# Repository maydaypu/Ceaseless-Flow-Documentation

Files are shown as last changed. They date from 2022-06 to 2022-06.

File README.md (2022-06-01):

# Ceaseless-Flow-Documentation
Ceaseless Flow is a decorative luminaire designed to bring tranquility to an acupuncture clinic waiting room.
By Josephine Wang and Jingyao Shao

This repository includes supplemental paperwork in PDF, 3D model CAD files, and PCB design files.

The 4chLED_PCB_Code.ino can be programmed on ATTINY84 via Arduino ISP. Learn more on https://github.com/SpenceKonde/ATTinyCore/blob/master/avr/extras/ATtiny_x4.md

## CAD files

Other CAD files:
CAD/Ceaseless Flow - Lamp Model.dwg

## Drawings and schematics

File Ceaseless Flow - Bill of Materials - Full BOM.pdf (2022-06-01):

Ceaseless Flow - Bill of Materials | Full BOM

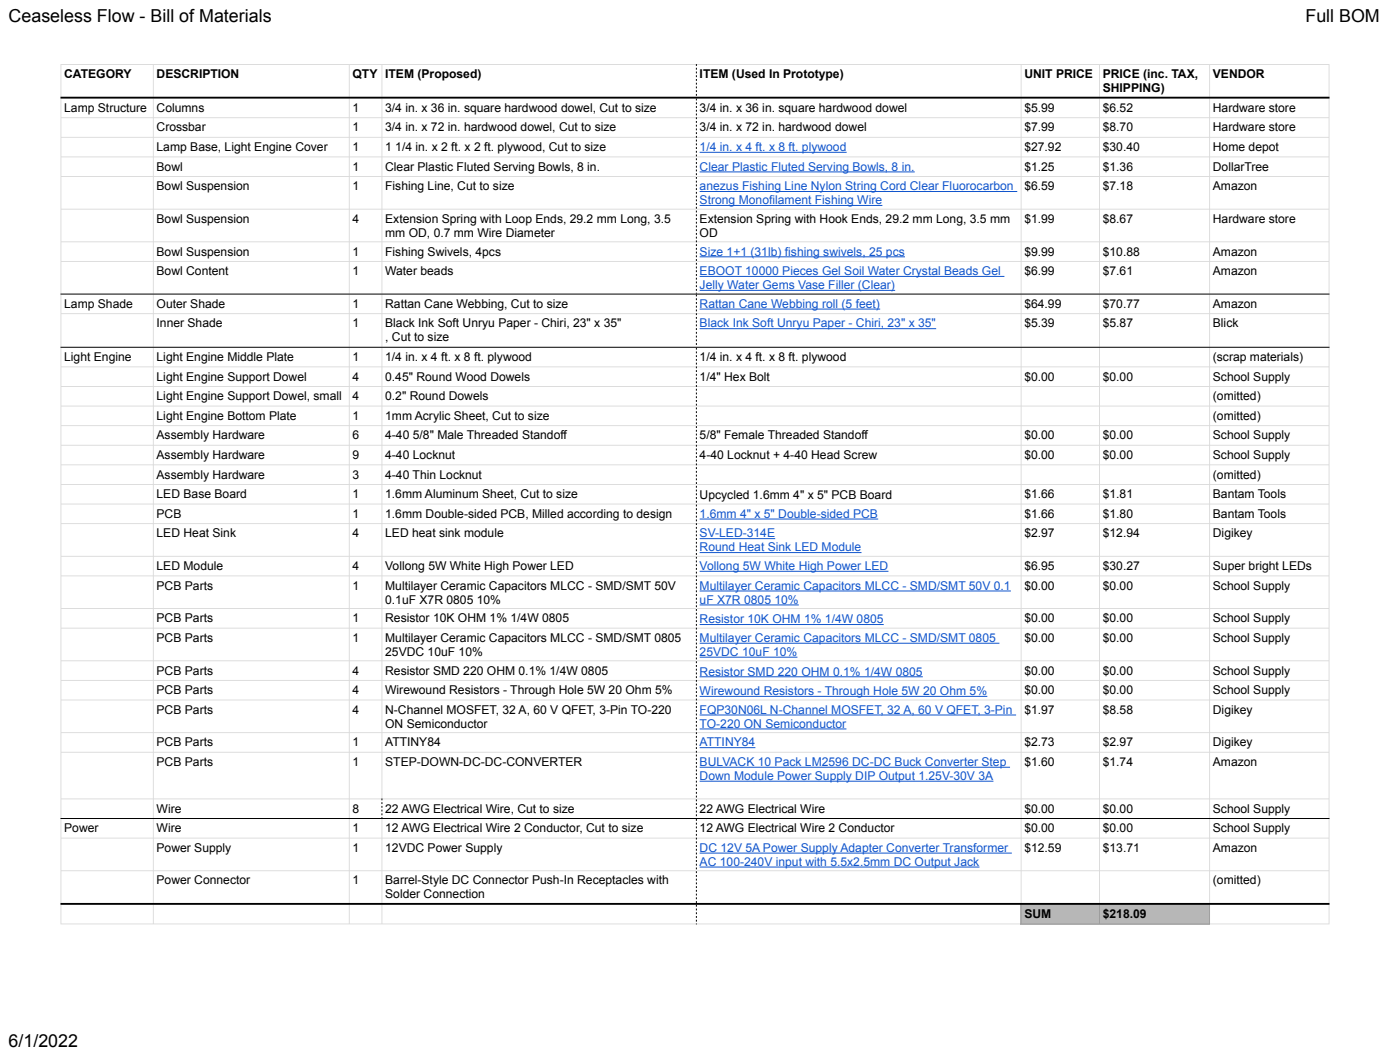
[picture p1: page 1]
CATEGORY; DESCRIPTION; QTY ITEM (Proposed); ITEM (Used In Prototype); UNIT PRICE PRICE (inc. TAX,; SHIPPING); VENDOR; Lamp Structure Columns; 3/4 in. x 36 in. square hardwood dowel, Cut to size; 3/4 in. x 36 in. square hardwood dowel; Hardware store; Crossbar; 3/4 in. x 72 in. hardwood dowel, Cut to size; 3/4 in. x 72 in. hardwood dowel; Lamp Base, Light Engine Cover; 1 1/4 in. x 2 ft. x 2 ft. plywood, Cut to size; 1/4 in. x 4 ft. x 8 ft. plywood; Home depot; Bowl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

Strong Monofilament Fishing Wire (https://www.amazon.com/Anezus-Fishing-String-Fluorocarbon-Monofilament/dp/B07J62FVCV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)
Extension Spring with Hook Ends, 29.2 mm Long, 3.5 mm

mm OD, 0.7 mm Wire Diameter

Jelly Water Gems Vase Filler (Clear) (https://www.amazon.com/gp/product/B01LXKOW8Y/ref=ppx_yo_dt_b_asin_title_o05_s00?ie=UTF8&psc=1)

, Cut to size

Round Heat Sink LED Module (https://www.digikey.com/en/products/detail/ohmite/SV-LED-314E/3768525)

Multilayer Ceramic Capacitors MLCC - SMD/SMT 50V 0.1

Multilayer Ceramic Capacitors MLCC - SMD/SMT 0805
25VDC 10uF 10% (https://www.mouser.com/ProductDetail/TDK/C2012X7S1E106K125AE?qs=P1JMDcb91o5L0SBQ9NWlYQ%3D%3D)

FQP30N06L N-Channel MOSFET, 32 A, 60 V QFET, 3-Pin
TO-220 ON Semiconductor (https://www.digikey.com/en/products/detail/onsemi/FQP30N06L/1055122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)

Down Module Power Supply DIP Output 1.25V-30V 3A

AC 100-240V input with 5.5x2.5mm DC Output Jack (https://www.amazon.com/dp/B01GEA8PQA?psc=1&ref=ppx_yo2ov_dt_b_product_details)

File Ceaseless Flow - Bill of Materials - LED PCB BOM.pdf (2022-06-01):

Ceaseless Flow - Bill of Materials | LED PCB BOM

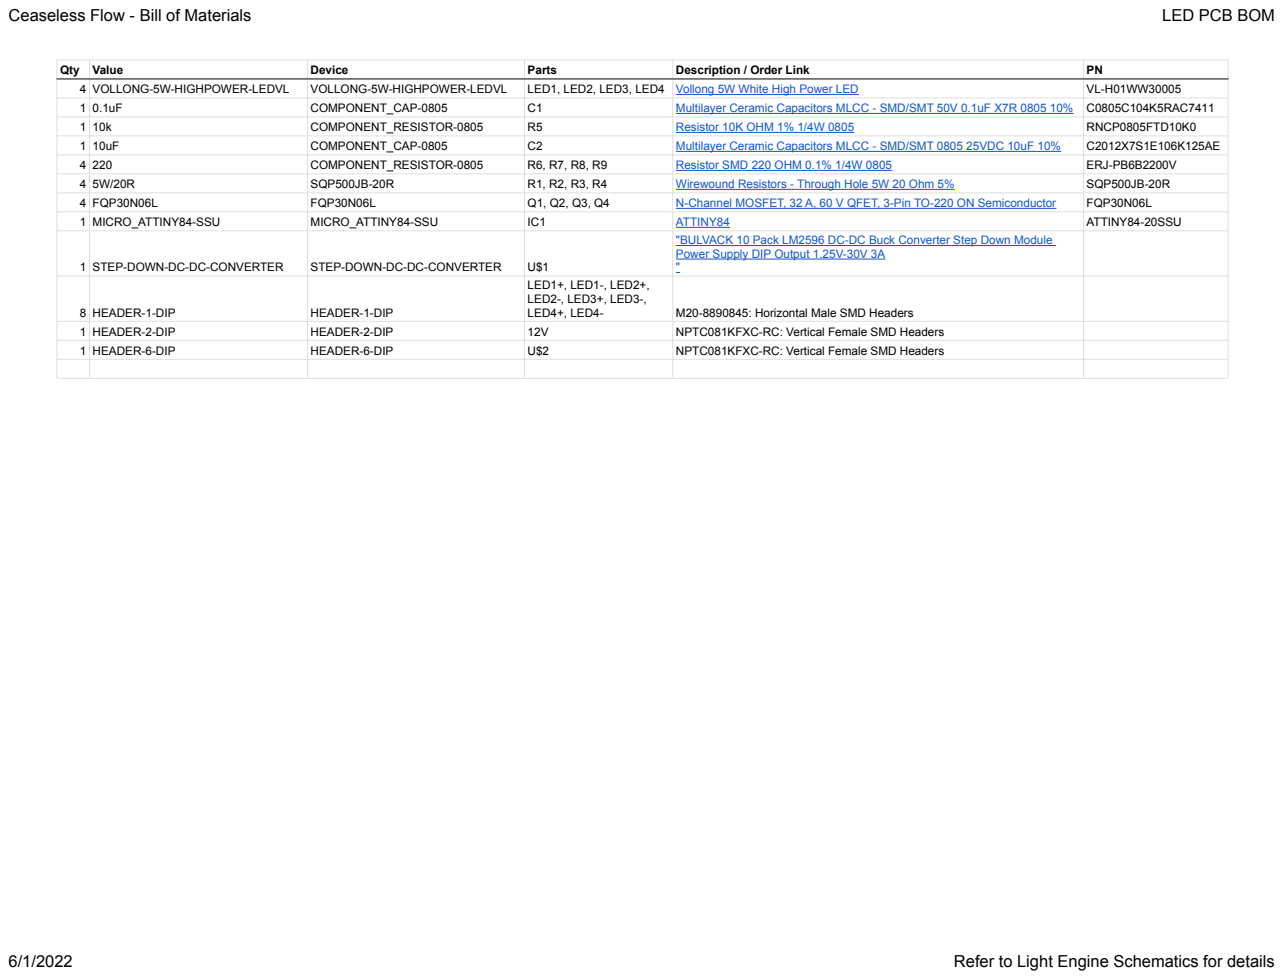
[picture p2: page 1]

"BULVACK 10 Pack LM2596 DC-DC Buck Converter Step Down Module
Power Supply DIP Output 1.25V-30V 3A

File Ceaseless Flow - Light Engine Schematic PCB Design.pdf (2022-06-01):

# Ceaseless Flow

Light Engine Schematic and PCB Design Overview

Designed by:
Josephine Wang and Jingyao Shao

Notes:
Refer to the file Bill of Materials, Sheet ‘LED PCB BOM’ for component specification.
Refer to the folder PCB for the EAGLE or Fusion PCB board design. The PCB can be made on a desktop PCB milling machine (https://www.bantamtools.com/pcb-milling-machine) or ordered from suppliers like OSHPark, (https://oshpark.com/) PCBWay. (https://www.pcbway.com/)
Refer to the file Lamp Construction Drawings, Sheet 3 - Light Engine Assembly Drawings for detailed assembly instruction.

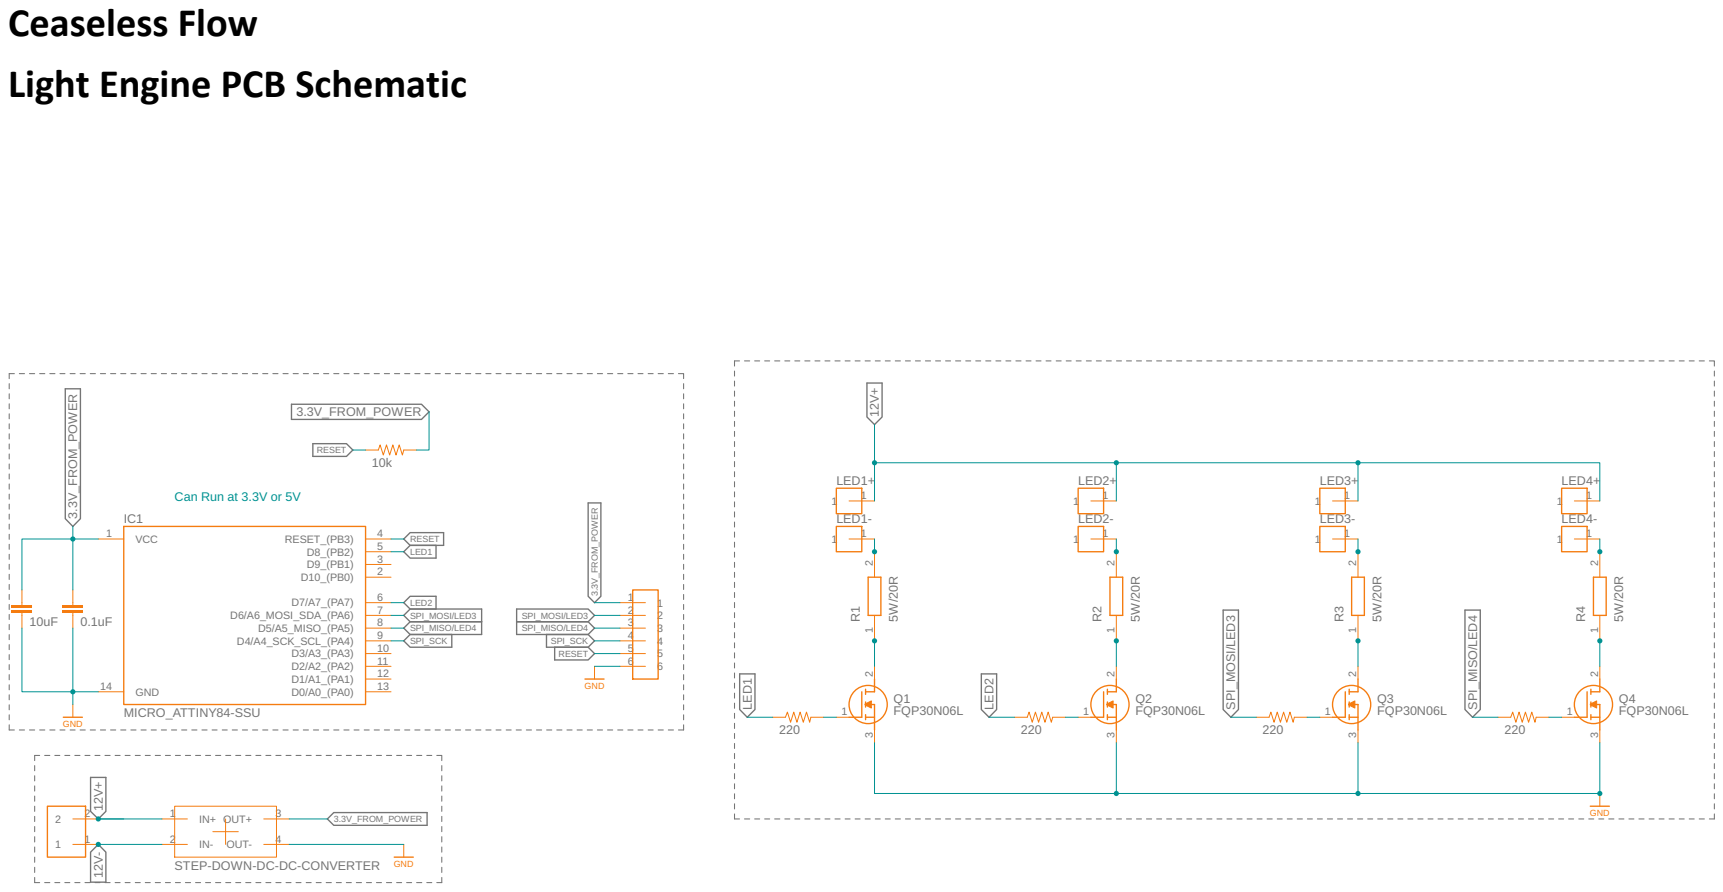
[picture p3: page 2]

Ceaseless Flow
Light Engine PCB Schematic

Can Run at 3.3V or 5V

STEP-DOWN-DC-DC-CONVERTER

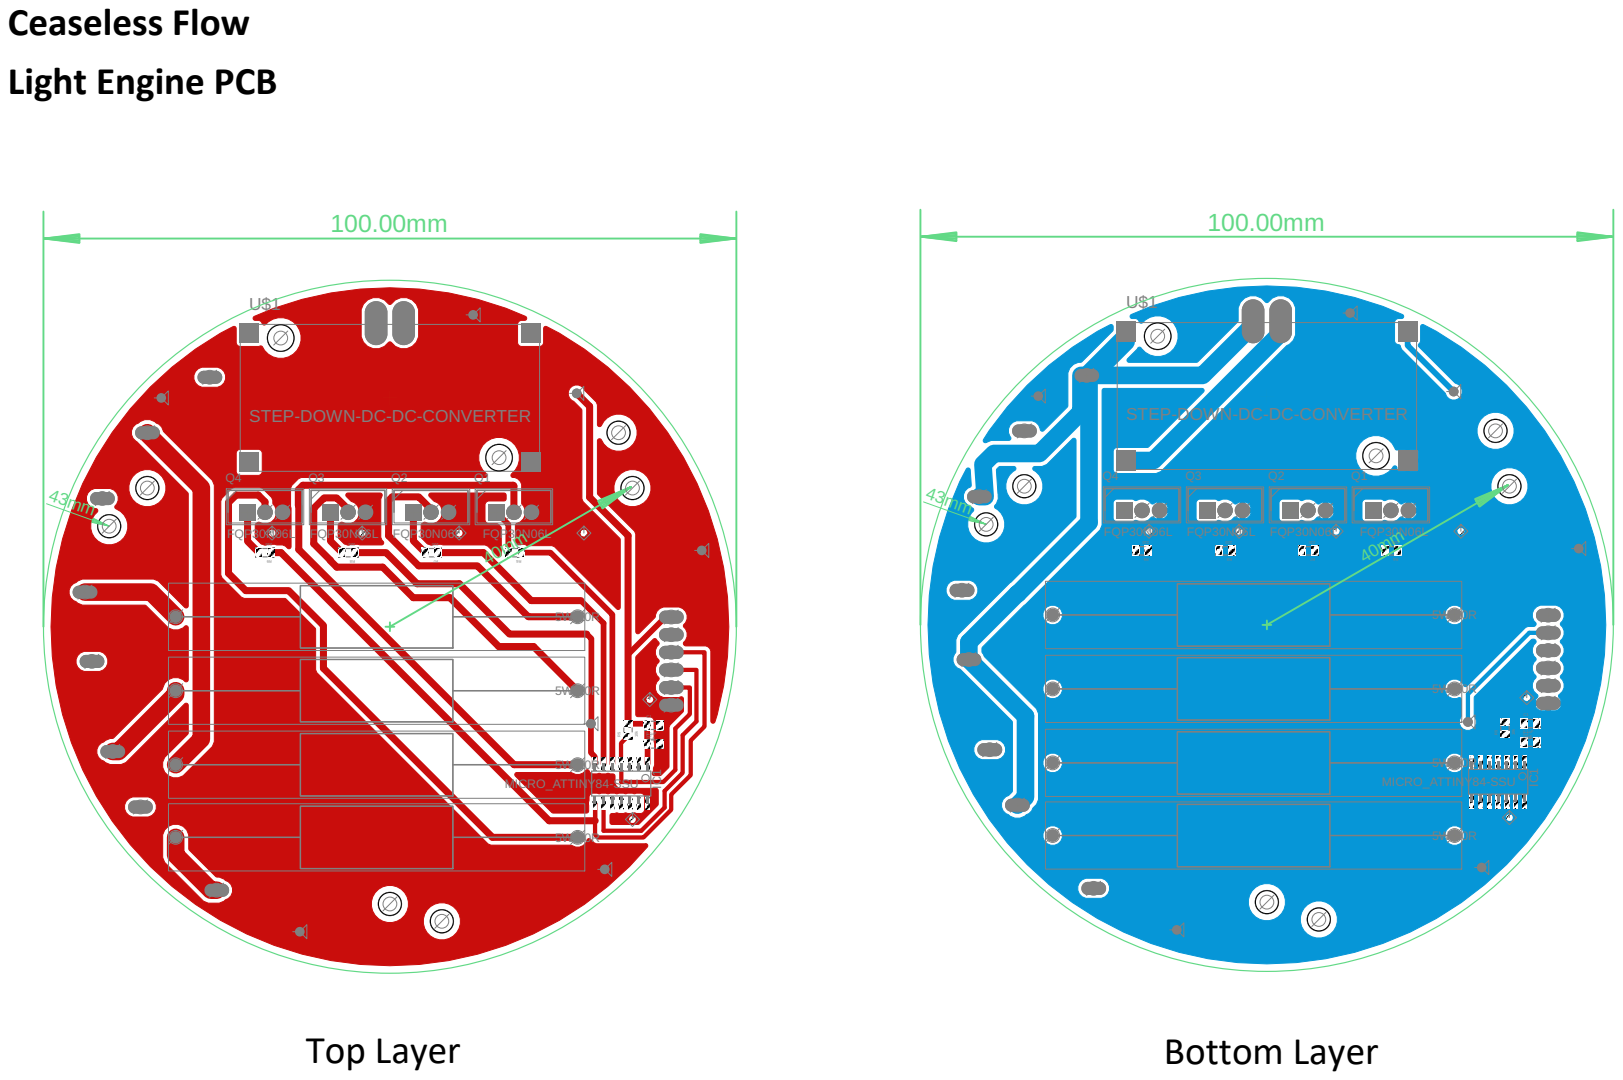
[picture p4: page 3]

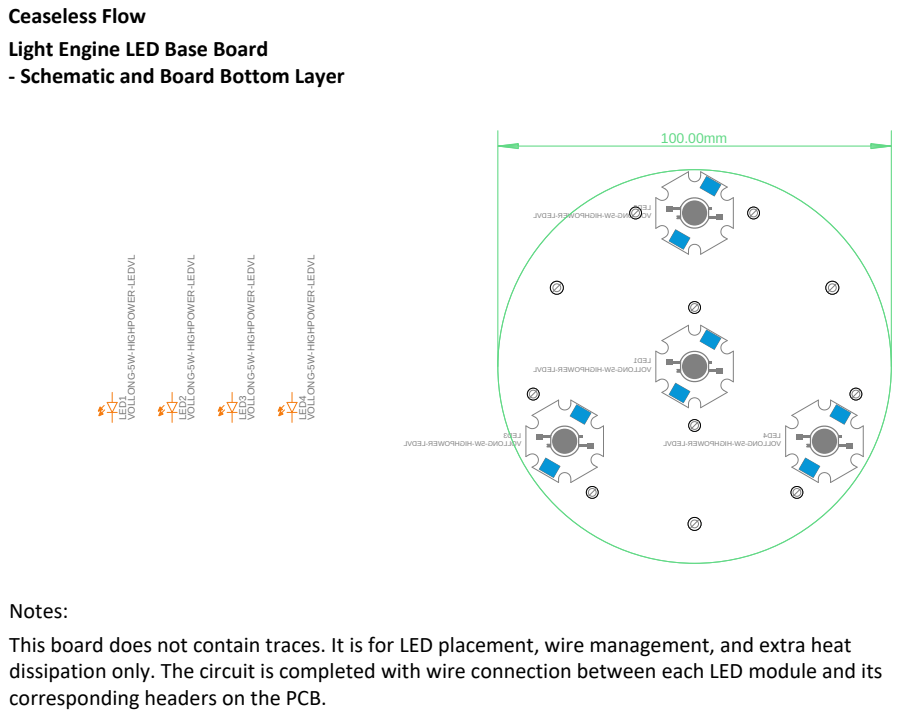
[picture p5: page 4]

Ceaseless Flow
Light Engine LED Base Board
- Schematic and Board Bottom Layer

LED1 VOLLONG-5W-HIGHPOWER-LEDVL LED2 VOLLONG-5W-HIGHPOWER-LEDVL LED3 VOLLONG-5W-HIGHPOWER-LEDVL LED4 VOLLONG-5W-HIGHPOWER-LEDVL

Notes:
This board does not contain traces. It is for LED placement, wire management, and extra heat
dissipation only. The circuit is completed with wire connection between each LED module and its
corresponding headers on the PCB.

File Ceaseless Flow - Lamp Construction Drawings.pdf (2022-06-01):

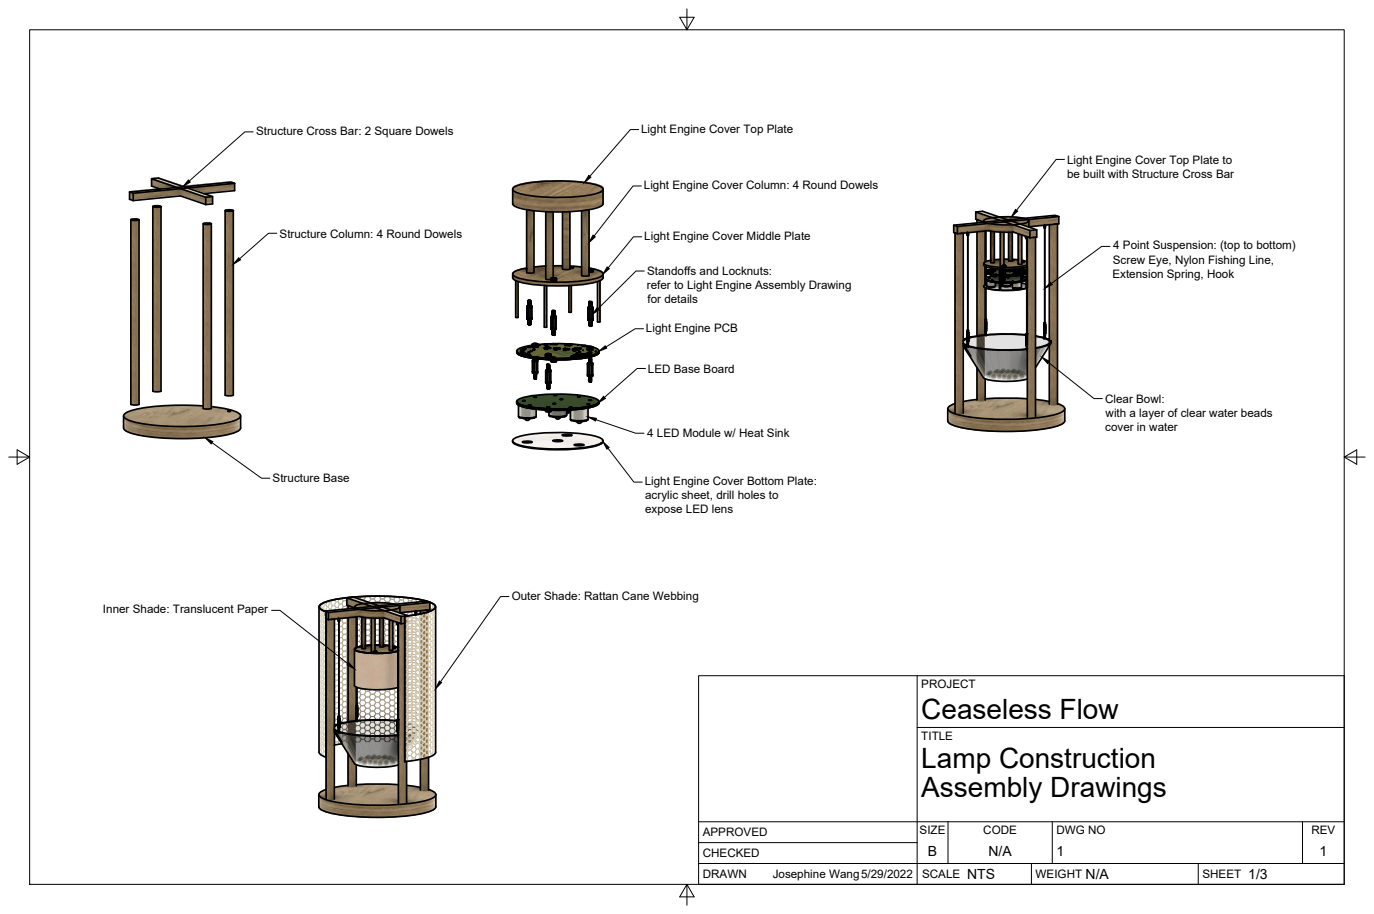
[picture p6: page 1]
SIZE; CODE; DWG NO; REV; Josephine Wang 5/29/2022; NTS; Ceaseless Flow; Assembly Drawings; Lamp Construction; Structure Base

Structure Cross Bar: 2 Square Dowels

Light Engine Cover Top Plate

Light Engine Cover Top Plate to
be built with Structure Cross Bar

Light Engine Cover Column: 4 Round Dowels

Structure Column: 4 Round Dowels

Light Engine Cover Middle Plate

4 Point Suspension: (top to bottom)
Screw Eye, Nylon Fishing Line,
Extension Spring, Hook

Standoffs and Locknuts:
refer to Light Engine Assembly Drawing
for details

Light Engine PCB

LED Base Board

Clear Bowl:
with a layer of clear water beads
cover in water

4 LED Module w/ Heat Sink

Light Engine Cover Bottom Plate:
acrylic sheet, drill holes to
expose LED lens

Outer Shade: Rattan Cane Webbing

Inner Shade: Translucent Paper

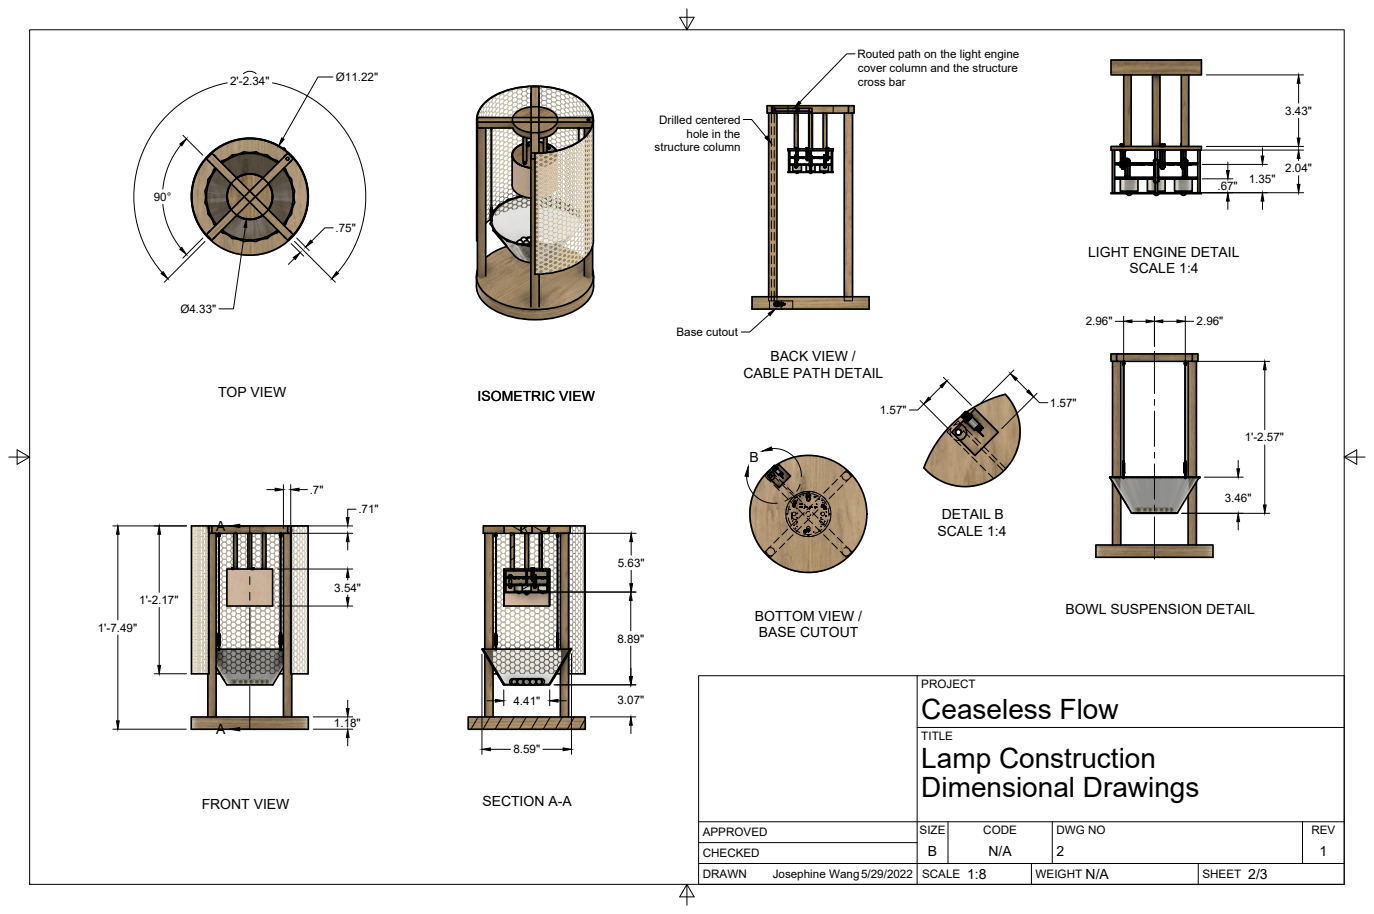
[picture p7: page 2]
SECTION A-A; SCALE 1:4; FRONT VIEW; TOP VIEW; ISOMETRIC VIEW; SIZE; CODE; DWG NO; REV; Josephine Wang 5/29/2022; Ceaseless Flow; Dimensional Drawings; Lamp Construction; DETAIL B SCALE 1:4; BOTTOM VIEW / BASE CUTOUT; Base cutout

Routed path on the light engine
cover column and the structure
cross bar

Drilled centered
hole in the
structure column

LIGHT ENGINE DETAIL

BACK VIEW /
CABLE PATH DETAIL

BOWL SUSPENSION DETAIL

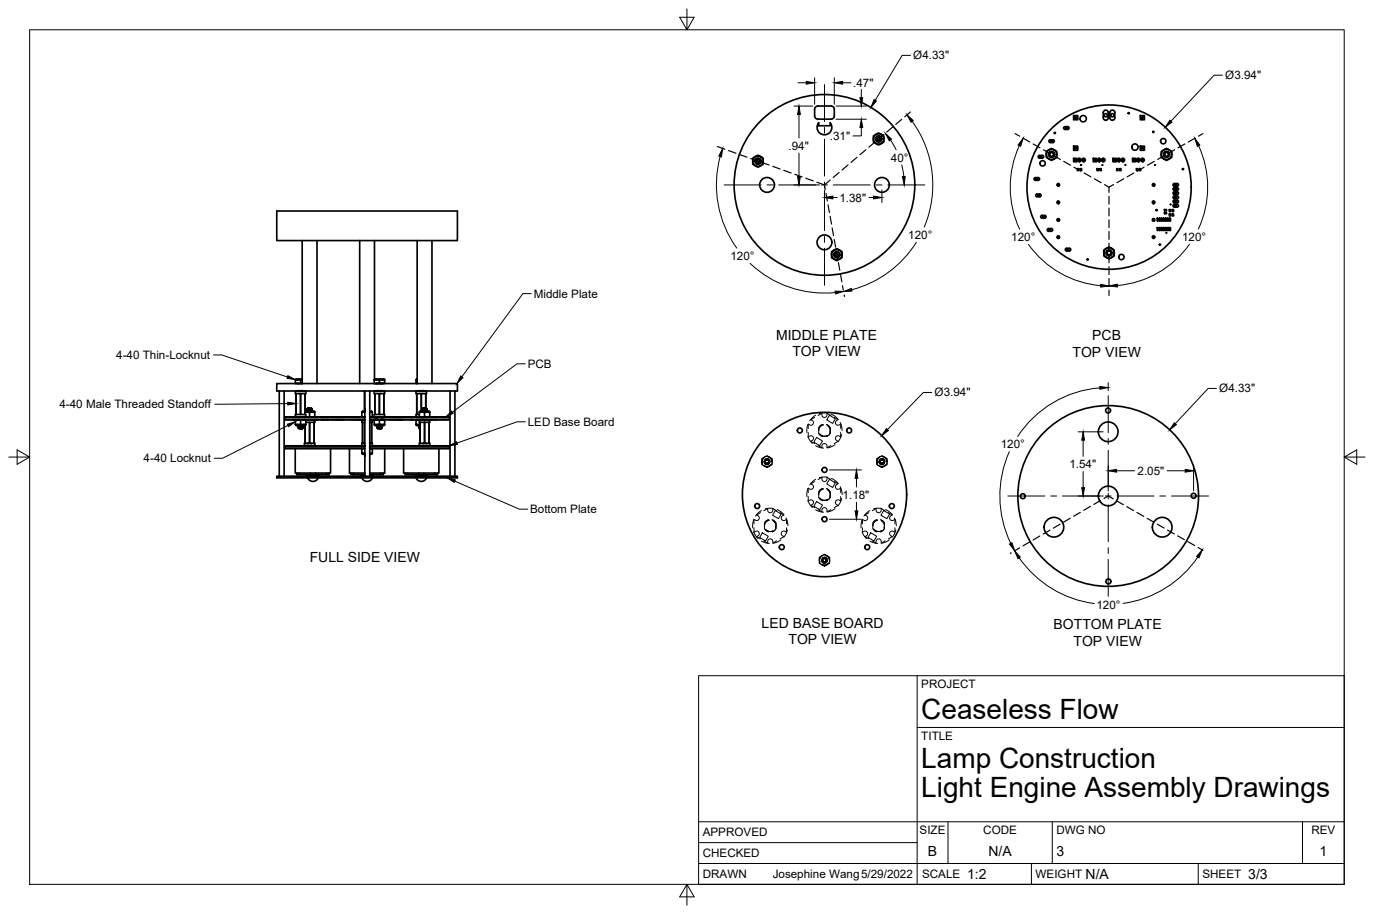
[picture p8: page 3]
SIZE; CODE; DWG NO; REV; Josephine Wang 5/29/2022; MIDDLE PLATE TOP VIEW; Middle Plate; Bottom Plate; TOP VIEW; BOTTOM PLATE TOP VIEW; 4-40 Thin-Locknut; 4-40 Locknut

4-40 Male Threaded Standoff

LED Base Board

FULL SIDE VIEW

LED BASE BOARD
TOP VIEW

PROJECT
Ceaseless Flow
Lamp Construction
Light Engine Assembly Drawings

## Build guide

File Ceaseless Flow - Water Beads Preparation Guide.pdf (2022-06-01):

# Ceaseless Flow

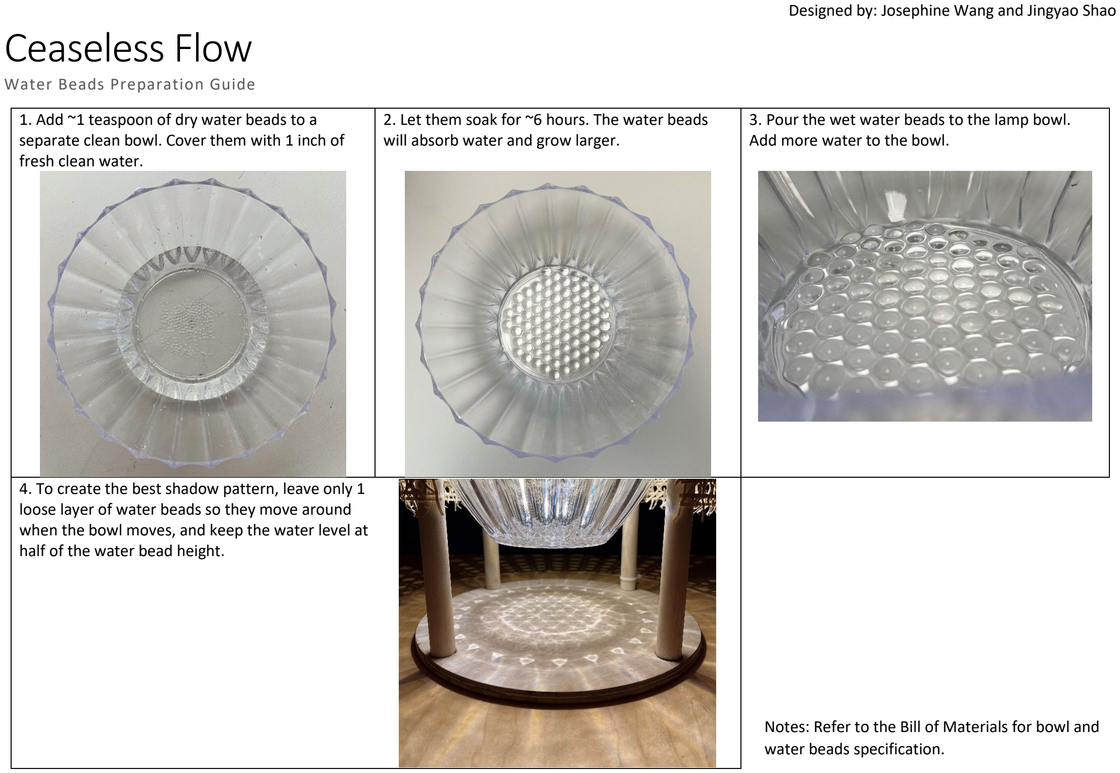
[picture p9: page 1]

Designed by: Josephine Wang and Jingyao Shao

Water Beads Preparation Guide
1. Add ~1 teaspoon of dry water beads to a separate clean bowl. Cover them with 1 inch of fresh clean water.
2. Let them soak for ~6 hours. The water beads will absorb water and grow larger.
3. Pour the wet water beads to the lamp bowl. Add more water to the bowl.
4. To create the best shadow pattern, leave only 1 loose layer of water beads so they move around when the bowl moves, and keep the water level at half of the water bead height.

Notes: Refer to the Bill of Materials for bowl and water beads specification.

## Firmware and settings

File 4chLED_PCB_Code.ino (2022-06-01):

const int LED1 = 8;
const int LED2 = 7;
const int LED3 = 6;
const int LED4 = 5;
int delayTime = 10;
int level = 0;
int fade = 1;
int mode = 1;
bool wasFull = false;

void setup() {
  pinMode(LED1, OUTPUT);
  pinMode(LED2, OUTPUT);
  pinMode(LED3, OUTPUT);
  pinMode(LED4, OUTPUT);
}

void loop() {
  if (mode == 1){
    analogWrite(LED1, 200);
    analogWrite(LED2, 0);
    analogWrite(LED3, 0);
    analogWrite(LED4, 0);
  } else if (mode == 2){
    analogWrite(LED1, 200);
    analogWrite(LED2, level);
    analogWrite(LED3, 0);
    analogWrite(LED4, 0);
  } else if (mode == 3){
    analogWrite(LED1, 200);
    analogWrite(LED2, level/2);
    analogWrite(LED3, level/2);
    analogWrite(LED4, 0);
  } else if (mode == 4){
    analogWrite(LED1, 200);
    analogWrite(LED2, level/3);
    analogWrite(LED3, level/3);
    analogWrite(LED4, level/3);
  } else if (mode == 5){
    analogWrite(LED1, 200);
    analogWrite(LED2, level/4);
    analogWrite(LED3, level/4);
    analogWrite(LED4, level/4);
  }
  
  level += fade;
  level = constrain(level, 0, 255);

  if (level >= 200){
    fade = -1;
    wasFull = true;
  }
  if (level <= 0 && wasFull == true){
    fade = 1;
    mode ++;
    wasFull = false;
  }
  if (mode >= 6){
    mode = 1;
  }
  
  delay(delayTime);
}
